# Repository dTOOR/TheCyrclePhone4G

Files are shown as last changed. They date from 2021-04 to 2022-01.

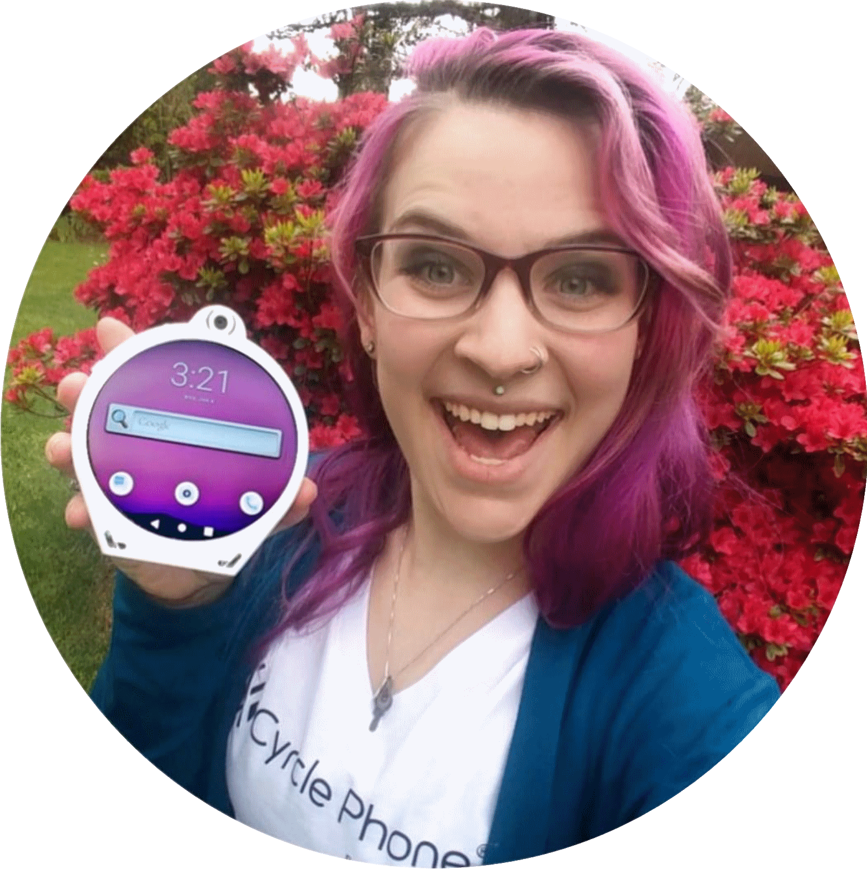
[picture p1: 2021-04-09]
Media/TeresaMicheletti_RoundPhoto_20200414.png

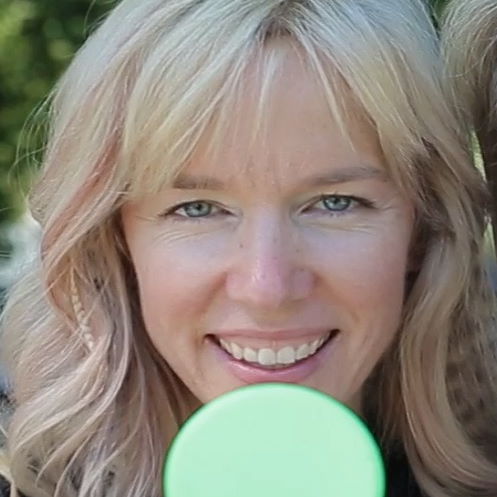
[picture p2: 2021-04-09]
Media/ChristinaGreenPhoneSquareJPG.jpg

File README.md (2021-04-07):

Welcome to the repository for The Cyrcle Phone 4G LTE.

HARDWARE:
Includes the schematics, board layout, and enclosure CAD files.

SOFTWARE:
Includes directions for creating the build.  

LICENSES:
A brief README.md overview and a copy of all the open source licenses which pertain to our product.

MEDIA:
Logos, brand guidelines, team photos

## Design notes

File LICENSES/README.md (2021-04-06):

<h1>LICENSES</h1>

<p>The Cyrcle Phone 4G LTE's software (including AOSP, Linux, and F-Droid) and hardware (including schematics, board layout, and enclosure CAD files) are shared with you under open source licenses, with some limitations due to closed source licenses we have had to sign with suppliers in order to obtain specific components. Mobile phones notoriously have a plethora of open source licenses and private driver licenses to maintain, for both the hardware and software. Communicating these licenses to our users in a clear manner is important to us. </p>

<h2>Open Source Software Licenses</h2>
<p>Below is a list of important open source software licenses which you should be aware of when you modify software provided here. 
We have provided this list to the best of our ability, and do not claim it is all-inclusive. 
We have includes samples of these licenses in our LICENSES folder, but please check with these organizations for the most updated version.</p>
<ul>
         <li>Apache 2.0 (Example: Android Open Source Project)</li>
         <li>GNU GPLv2 (Example: Linux kernel patches)</li>
         <li>GNU GPLv3 (Example: F-Droid)</li>
         <li>Mozilla Public License 2.0 (Example: Firefox, Lightning Browser)</li>
</ul>

<h2>Open Source Hardware Licenses</h2>
<p>Below is a list of important open source hardware licenses which you should be aware of when you modify any open source hardware.
We have provided this list to the best of our ability, and do not claim it is all-inclusive. 
We have includes samples of these licenses in our LICENSES folder, but please check with these organizations for the most updated version.</p>
<ul>
         <li>CERN - Now available in 3 flavors: CERN-OHL-P (permissive), CERN-OHL-W (weakly reciprocal), and CERN-OHL-S (strongly reciprocal)
         Developed by the org which created the world wide web</li>
         <li>TAPR - Tucson Amateur Packet-Radio Open Hardware license, by John Ackerman and FOSS' Bruce Perens</li>
         <li>Solderpad - basically Apache 2.0 but for hardware, by Andrew Katz</li>
         <li>TDPL  - Three-Dimensional Printing Open license by Eli Greenbaum (for enclosures)</li>
         <li>CC by SA - Adafruit, Sparkfun, and Arduino utilize this license</li>
</ul>

<p>It is important to note that The Cyrcle Phone 4G LTE's hardware (including schematics, board layout, and enclosure CAD files) are shared with you under an open source license, with some limitations due to the closed source licenses we have had to sign with suppliers in order to obtain specific components. </p>

<h2>Closed Source Hardware and Software Licenses</h2>
<p>Below is a list of important private licenses which our company has had to sign along our journey of making The Cyrcle Phone 4G LTE of which you should be aware, and which we may not be able to share out to you.
We have provided this list to the best of our ability, and do not claim it is all-inclusive. </p>
<ul>
         <li>Quectel Wireless Solutions Co., Ltd. (Includes the module technology)</li>
         <li>Tianma Microelectronics Co. (Includes the display and touchscreen technology)</li>
</ul>

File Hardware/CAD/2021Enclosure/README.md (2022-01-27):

<p>These are the STL and STEP files for 2021 The Cyrcle Phone 4G enclosure.</p>

<p>Additional Materials Needed:</p>
Uses the following eight (8) McMaster Carr screws (4 for the skeleton, 4 for the back shell)
- 5mm Screws: JIS Steel Flat Head Screws, M1.6 x 0.35 mm Thread, 5mm Long, 91305A004 https://www.mcmaster.com/catalog/127/3293/

<br><p>Tips for printing:</p>
- Calibrate your machine first. The walls are thin and will test your 3D printer's tolerances.
- Print the "back shell" separately, face down, and use rectilinear supports inside to make the back of the shell smooth. Use pliers to grab and twist the support material out from the inside of the "back shell". The inside will end up being rough, but the outside smoothness will feel nice in the hand.
- Print the "faceplate" face down on a glassy surface for a nice and smooth face. We typically use a contrasting color (black) for this piece, and consequently have to print it separately.
- Print the "outer ring" with the tabs up, face down, because you will want the face of the "outer ring" to be smooth, and allow the slight indentations for the ports to print well on top. (You can sand away any irregularities that may occur with the tabs later since they end up hidden in the design.)

<br><p>History:</p>
<br>In July 2020, industrial designer Wesley Millora submitted an entry for The Cyrcle Phone 4G enclosure contest held on MyMiniFactory and won "Best Exterior" out of 64 submissions.
<br>In September 2020, dTOOR solicited Millora for a bid to update the design for injection molding purposes, which he then submitted.
<br>Months rolled by as dTOOR continued to work on software development.
<br>In late December 2020, Millora was contacted by dTOOR Founder & CEO Christina Cyr, formerly asking him to join the team. Since Millora was on vacation, and working on another project at the time, Cyr also asked permission to use Millora's design in the meantime, since units needed to be submitted to China for testing by January 10th.
<br>In short, these files were created by dTOOR Founder & CEO Christina Cyr in January 2021, specifically based on (and only after obtaining consent) Wesley Millora's images submitted for The Cyrcle Phone 4G enclosure design contest on MyMiniFactory, with the intention of Millora joining the team at a later date when he was available. Millora joined the team in March 2021 to update the design for injection molding purposes.
<br>As such, these files are not absolutely identical to the final product, as they have been designed to print (more) reliably on a 3D printer (slightly thicker walls, no 3% wall incline required for injection molding, etc.). These 3D-printer-friendly files were used for all of our evaluation models. In our experience, these files can be printed fairly reliabily with most PLA filaments on most 3D printers, so that you can have any color (or sparkle) you want. These files are also provided to you so that you can enhance the design to better fit your style (rabbit ears, etc.). We would love it if you could share photos of your designs on social media and tag us at #cyrclephone so that we can see what you've added. Have fun!

Licenses:
- The enclosure CAD files are shared under CERN-OHL-W-2.0 open hardware license. https://ohwr.org/project/cernohl/wikis/faq#q-what-are-all-these-suffixes
- This documentation is shared under CC BY-SA 2.0 open license. https://creativecommons.org/licenses/by-sa/2.0/

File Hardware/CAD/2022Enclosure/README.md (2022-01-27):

README.md
These are the STL files for 2022 The Cyrcle Phone 4G enclosure.

Additional Materials Needed:

Uses the following eight (8) McMaster Carr screws (4 for the skeleton, 4 for the back shell) - 5mm Screws: JIS Steel Flat Head Screws, M1.6 x 0.35 mm Thread, 5mm Long, 91305A004 https://www.mcmaster.com/catalog/127/3293/

Tips for printing:

Calibrate your machine first. The walls on this model are thin and will test your 3D printer's tolerances.
Print the "back shell" separately, face down, and use rectilinear supports inside the concave shape to the build platform in order to make the back of the shell smooth. After printing, use pliers to grab and twist the support material out from the inside of the "back shell". The inside will end up being rough, but the outside smoothness will feel nice in the hand.
Print the "faceplate" face down on a glassy surface for a nice and smooth face. We typically use a contrasting color (black) for this piece, and consequently have to print it separately.
Print the "outer ring" with the tabs up, face down, because you will want the face of the "outer ring" to be smooth, and allow the slight indentations for the ports to print well on top. (You can sand away any irregularities that may occur with the tabs later since they end up hidden in the design.)
Print the "skeleton" and "buttons" in any color or material; these are reliable prints on basically any setting.

History:

In July 2020, industrial designer Wesley Millora submitted an entry for The Cyrcle Phone 4G enclosure contest held on MyMiniFactory and won "Best Exterior" out of 64 submissions.
In September 2020, dTOOR solicited Millora for a bid to update the design for injection molding purposes, which he then submitted.
Months rolled by as dTOOR continued to work on software development.
In late December 2020, Millora was contacted by dTOOR Founder & CEO Christina Cyr, formerly asking him to join the team. Since Millora was on vacation, and working on another project at the time, Cyr also asked permission to use Millora's design in the meantime, since units needed to be submitted to China for testing by January 10th.
Millora worked on preparing a design appropriate for injection molding throughout 2021, with his final submission to dTOOR in December 2021. Cyr modified these final files to create a newer 3D printable design.
These 3D-printer-friendly files were used for evaluation models, and one unit was even demonstrated at The Cyrcle Phone booth at CES2022 with positive response. 
In our experience, these files can be printed fairly reliabily with most PLA filaments on most 3D printers, so that you can have any color (or sparkle) you want. These files are also provided to you so that you can enhance the design to better fit your style (rabbit ears, etc.). We would love it if you could share photos of your designs on social media and tag us at #cyrclephone so that we can see what you've added. Have fun!
Licenses:

The enclosure CAD files are shared under CERN-OHL-W-2.0 open hardware license. https://ohwr.org/project/cernohl/wikis/faq#q-what-are-all-these-suffixes
This documentation is shared under CC BY-SA 2.0 open license. https://creativecommons.org/licenses/by-sa/2.0/

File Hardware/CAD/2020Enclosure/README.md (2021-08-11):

These are the files dTOOR Founder & CEO Christina Cyr designed for The Cyrcle Phone 4G enclosure for The Cyrcle Phone booth at CES2020. Important note: This model accommodates the older Tequila PCB, but does not accommodate the new temperature sensor hardware near the selfie camera on the newer Mezcal PCB. We recommend widening the selfie camera housing to accommodate this change, or using the 2021enclosure. 

This model uses the following two (2) McMaster Carr threaded inserts and four (4) screws.

- Threaded inserts: Tapered Heat-Set Inserts For Plastic, Brass, M1.6 x 0.35 Mm Thread Size, 2.92 Mm Installed Length, 94180A501 https://www.mcmaster.com/catalog/127/3569
- 4mm Screws: JIS Steel Flat Head Screws, M1.6 x 0.35 mm Thread, 4mm Long, 91305A003 https://www.mcmaster.com/catalog/127/3293/

Licenses:
- The enclosure CAD files are shared under CERN-OHL-W-2.0 open hardware license. https://ohwr.org/project/cernohl/wikis/faq#q-what-are-all-these-suffixes
- This documentation is shared under CC BY-SA 2.0 open license. https://creativecommons.org/licenses/by-sa/2.0/

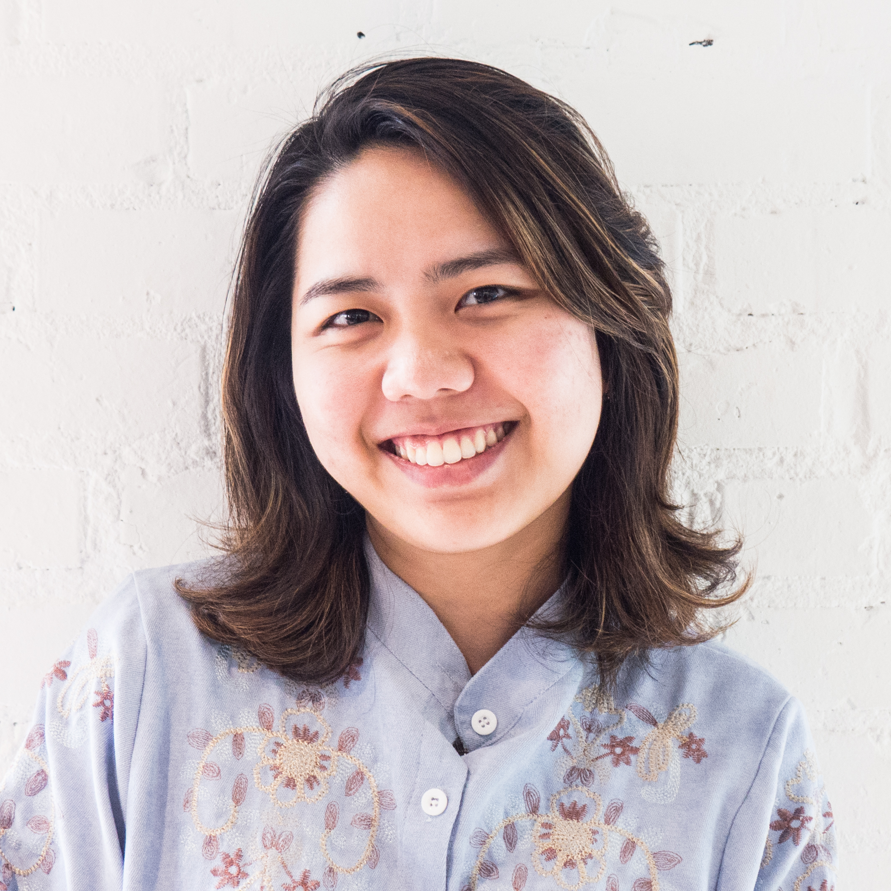
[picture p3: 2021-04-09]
Media/Mai-Dang-Headshot-Publish.jpg

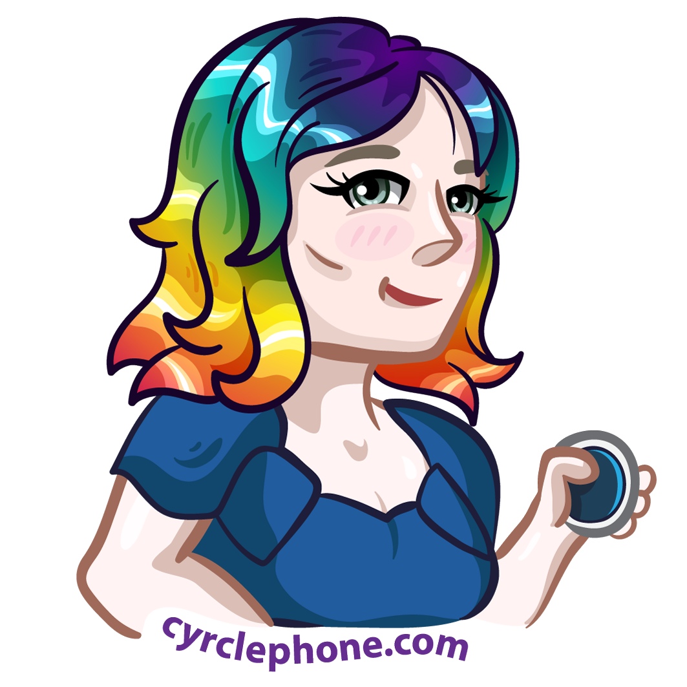
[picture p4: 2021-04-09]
Media/Sticker.png

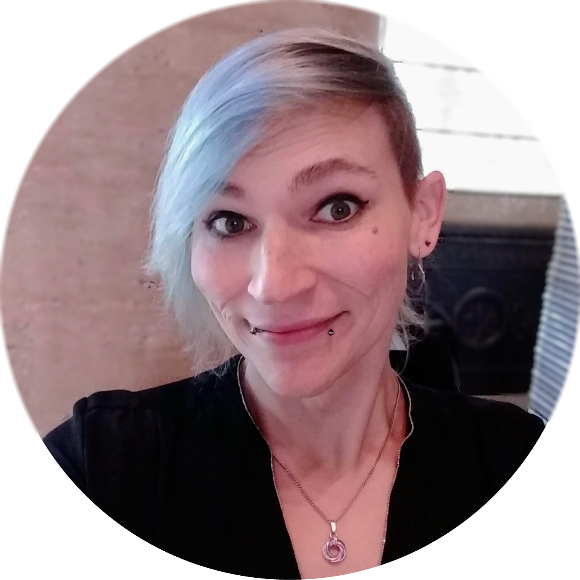
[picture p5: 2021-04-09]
Media/AddisonKarolick.png

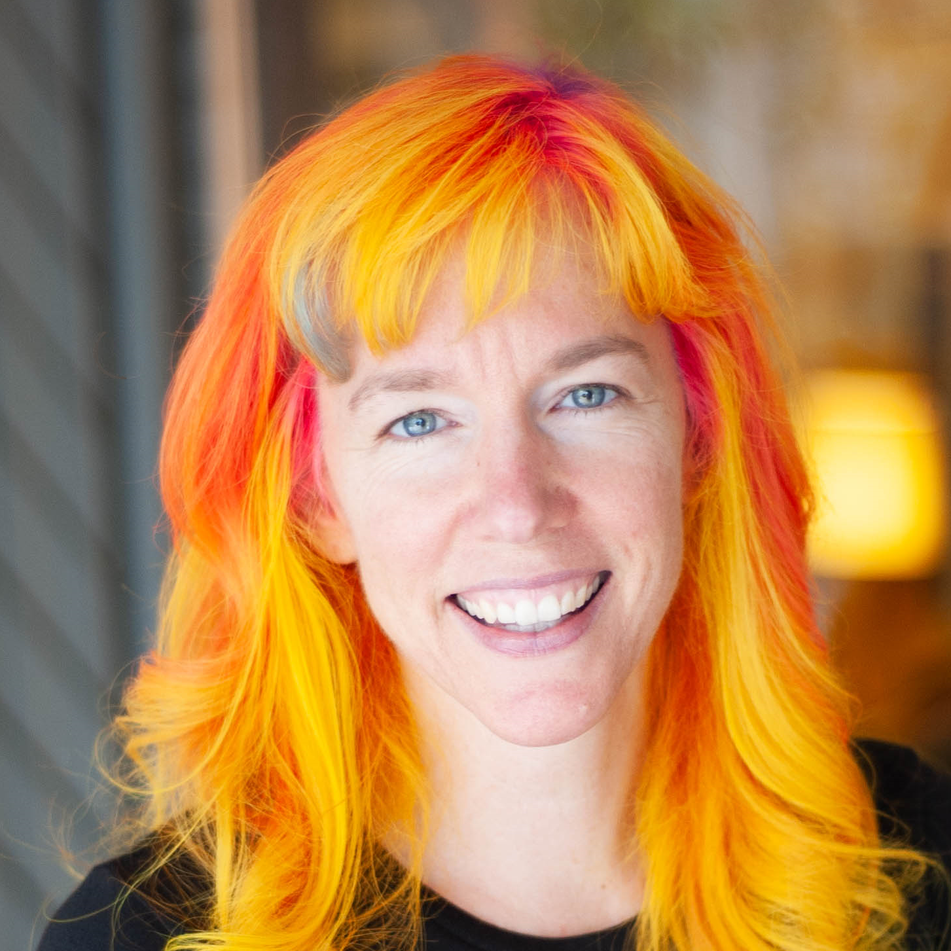
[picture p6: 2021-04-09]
Media/ChristinaCyr_Square.png

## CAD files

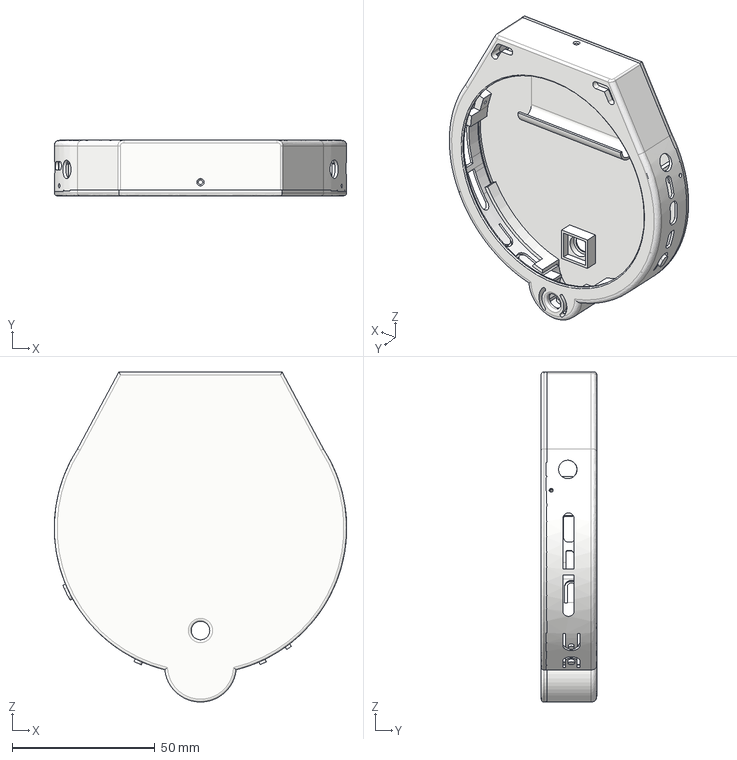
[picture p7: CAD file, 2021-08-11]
Hardware/CAD/2020Enclosure/STEPs/Tequila_20191217_enclosure_20200106 v64.step
102.6 x 19.5 x 115.8 mm

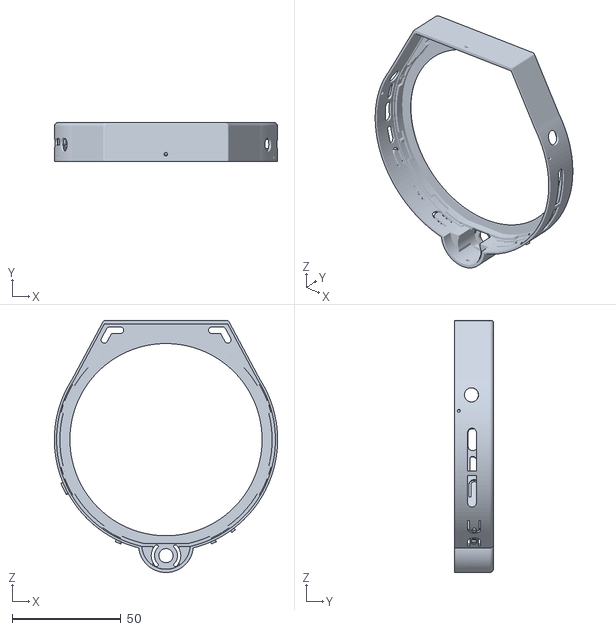
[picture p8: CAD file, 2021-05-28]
Hardware/CAD/2020Enclosure/STLs/Front_20191217_enclosure_20200106 v58.stl
102.6 x 18.0 x 115.8

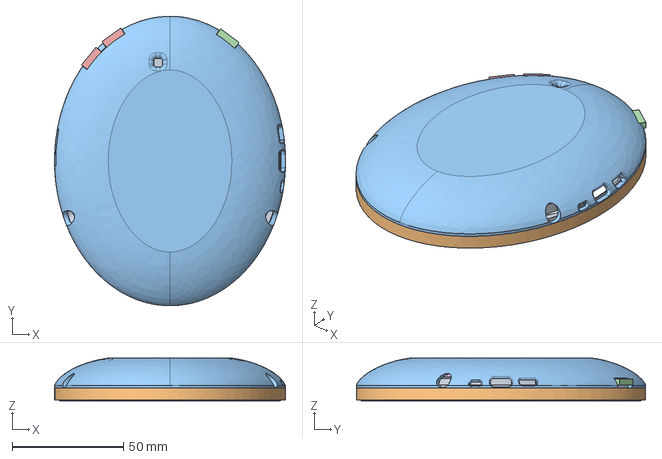
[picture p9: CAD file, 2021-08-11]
Hardware/CAD/2021Enclosure/STEPs/TheCyrclePhone_Mezcal_Oval4 v13.step
103.9 x 130.1 x 19.2 mm

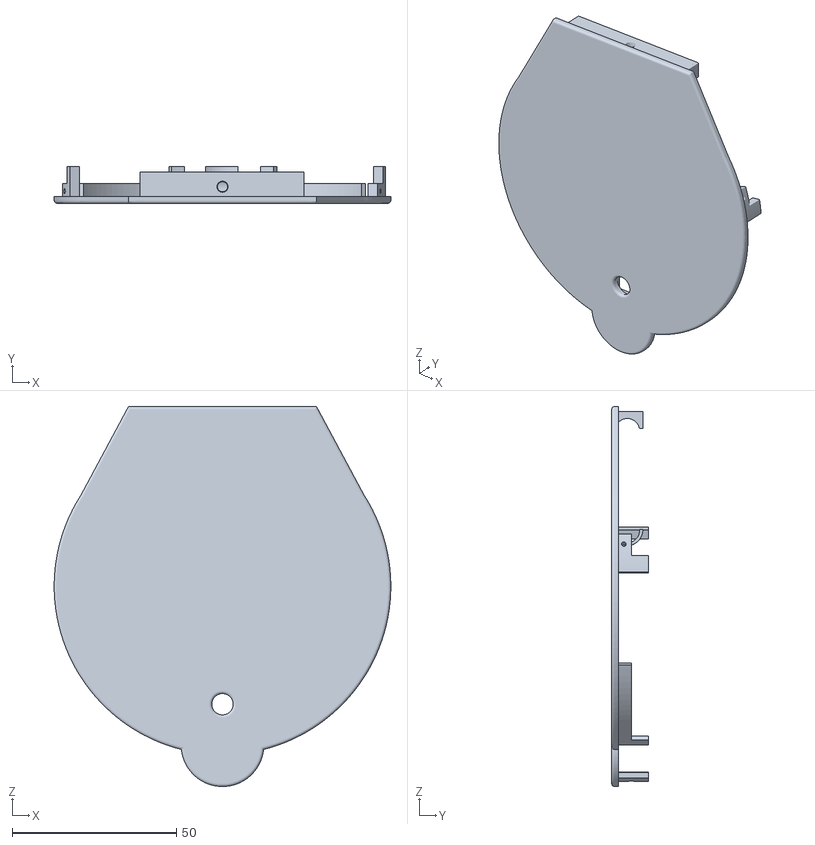
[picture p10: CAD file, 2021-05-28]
Hardware/CAD/2020Enclosure/STLs/Back_20191217_enclosure_20200106 v48.stl
102.6 x 11.2 x 115.8

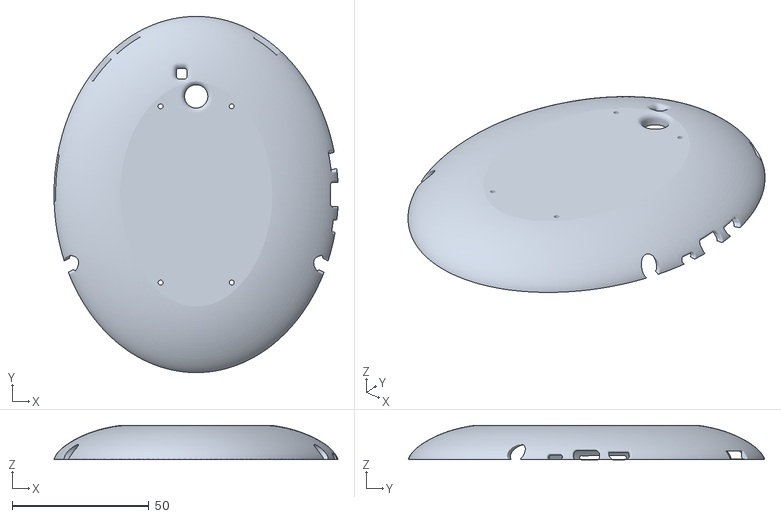
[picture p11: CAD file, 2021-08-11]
Hardware/CAD/2021Enclosure/STLs/20210310_BackShell.stl
103.8 x 130.1 x 12.5

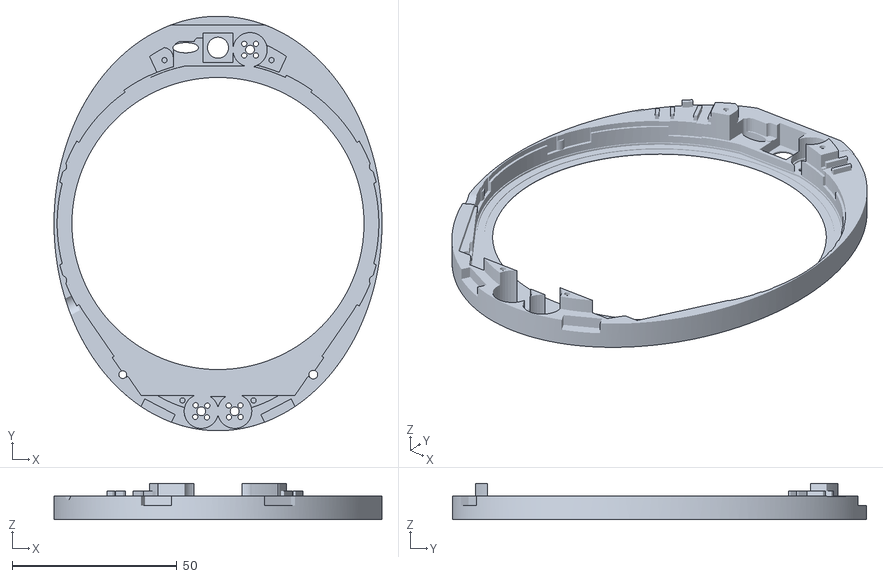
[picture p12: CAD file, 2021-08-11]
Hardware/CAD/2021Enclosure/STLs/20210619_Faceplate.stl
99.5 x 125.7 x 11.0

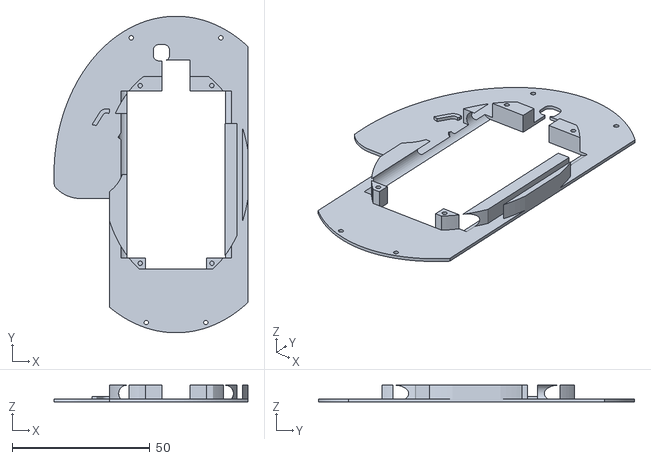
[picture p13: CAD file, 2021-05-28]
Hardware/CAD/2021Enclosure/STLs/20210414_Skeleton.stl
70.3 x 114.7 x 6.00

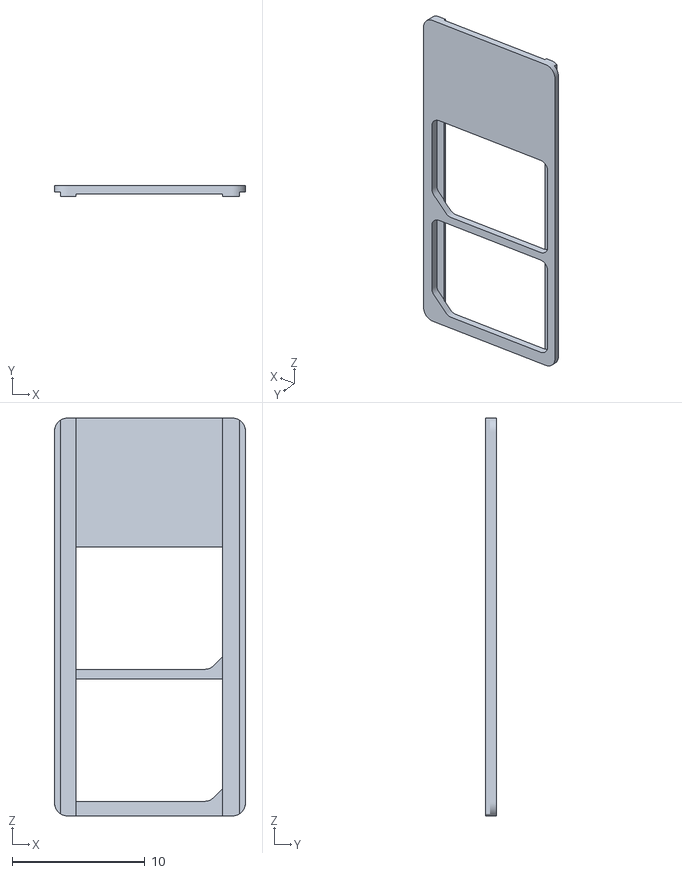
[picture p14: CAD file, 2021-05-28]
Hardware/CAD/2021Enclosure/STLs/20210111_SIMcardtray.stl
14.4 x 0.85 x 30.0

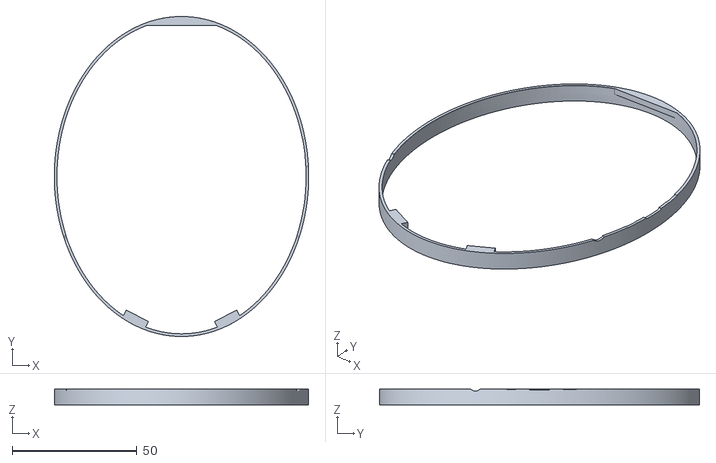
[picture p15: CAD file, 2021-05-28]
Hardware/CAD/2021Enclosure/STLs/20210407_FrontRing_with_HeadphoneJack_holes.stl
101.9 x 128.1 x 6.34

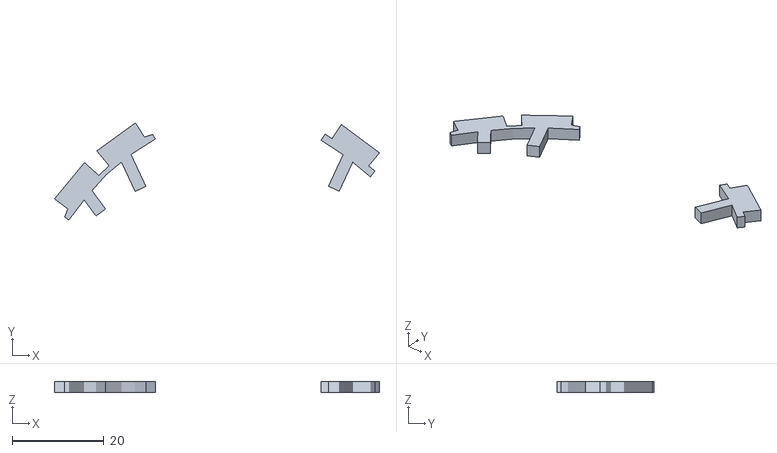
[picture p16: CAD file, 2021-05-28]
Hardware/CAD/2021Enclosure/STLs/20210105_Buttons.stl
70.9 x 21.2 x 2.50

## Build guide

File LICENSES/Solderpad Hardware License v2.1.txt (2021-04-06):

Solderpad Hardware License v2.1
This license operates as a wraparound license to the Apache License Version 2.0 (the “Apache License”) and incorporates the terms and conditions of the Apache License (which can be found here: http://apache.org/licenses/LICENSE-2.0), with the following additions and modifications. It must be read in conjunction with the Apache License. Section 1 below modifies definitions and terminology in the Apache License and Section 2 below replaces Section 2 of the Apache License. The Appendix replaces the Appendix in the Apache License. You may, at your option, choose to treat any Work released under this license as released under the Apache License (thus ignoring all sections written below entirely).

1. Terminology in the Apache License is supplemented or modified as follows:

“Authorship”: any reference to ‘authorship’ shall be taken to read “authorship or design”.

“Copyright owner”: any reference to ‘copyright owner’ shall be taken to read “Rights owner”.

“Copyright statement”: the reference to ‘copyright statement’ shall be taken to read ‘copyright or other statement pertaining to Rights’.

The following new definition shall be added to the Definitions section of the Apache License:

“Rights” means copyright and any similar right including design right (whether registered or unregistered), rights in semiconductor topographies (mask works) and database rights (but excluding Patents and Trademarks).

The following definitions shall replace the corresponding definitions in the Apache License:

“License” shall mean this Solderpad Hardware License version 2.1, being the terms and conditions for use, manufacture, instantiation, adaptation, reproduction, and distribution as defined by Sections 1 through 9 of this document.

“Licensor” shall mean the owner of the Rights or entity authorized by the owner of the Rights that is granting the License.

“Derivative Works” shall mean any work, whether in Source or Object form, that is based on (or derived from) the Work and for which the editorial revisions, annotations, elaborations, or other modifications represent, as a whole, an original work of authorship or design. For the purposes of this License, Derivative Works shall not include works that remain reversibly separable from, or merely link (or bind by name) or physically connect to or interoperate with the Work and Derivative Works thereof.

“Object” form shall mean any form resulting from mechanical transformation or translation of a Source form or the application of a Source form to physical material, including but not limited to compiled object code, generated documentation, the instantiation of a hardware design or physical object or material and conversions to other media types, including intermediate forms such as bytecodes, FPGA bitstreams, moulds, artwork and semiconductor topographies (mask works).

“Source” form shall mean the preferred form for making modifications, including but not limited to source code, net lists, board layouts, CAD files, documentation source, and configuration files.

“Work” shall mean the work of authorship or design, whether in Source or Object form, made available under the License, as indicated by a notice relating to Rights that is included in or attached to the work (an example is provided in the Appendix below).

2. Grant of License. Subject to the terms and conditions of this License, each Contributor hereby grants to You a perpetual, worldwide, non-exclusive, no-charge, royalty-free, irrevocable license under the Rights to reproduce, prepare Derivative Works of, make, adapt, repair, publicly display, publicly perform, sublicense, and distribute the Work and such Derivative Works in Source or Object form and do anything in relation to the Work as if the Rights did not exist.

APPENDIX

Copyright [yyyy] [name of copyright owner]
SPDX-License-Identifier: Apache-2.0 WITH SHL-2.1

Licensed under the Solderpad Hardware License v 2.1 (the “License”); you may not use this file except in compliance with the License, or, at your option, the Apache License version 2.0. You may obtain a copy of the License at

https://solderpad.org/licenses/SHL-2.1/

Unless required by applicable law or agreed to in writing, any work distributed under the License is distributed on an “AS IS” BASIS, WITHOUT WARRANTIES OR CONDITIONS OF ANY KIND, either express or implied. See the License for the specific language governing permissions and limitations under the License.

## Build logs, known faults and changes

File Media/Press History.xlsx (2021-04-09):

Date Published | Channel & Article Link | Journalist | Key Quote
2016-12-14 | King 5 Evening News (https://www.king5.com/article/entertainment/television/programs/evening/seattles-startup-community-sticks-together/281-369995036) | Saint Bryan | "To work for yourself, you kinda need to be scrappy, so you gotta get in there with some grit and tenacity because it's really lonely," Cyr says.
2016-03-11 | Business Insider (https://www.businessinsider.com/what-is-cyrcle-phone-2016-3) | Rafi Letzter | What does a smartphone look like? A rectangle, about the size of an index card, usually either white, black, or chrome.
2016-03-03 | Independent UK (https://www.independent.co.uk/life-style/gadgets-and-tech/news/cyrcle-round-circle-circular-smartphone-dtoor-mobile-world-congress-a6909306.html) | Doug Bolton | The Cyrcle phone is designed to be more elegant and ladylike than its rectangular competitors
2016-02-29 | 3ders.org (https://www.3ders.org/articles/20160229-cyrcle-the-3d-printed-circular-smartphone-is-anything-but-square.html) | Tess Boissonneault | Whether you are partial to iPhones, or prefer Samsungs, HTC’s, or LG’s, it is hard to escape one common factor between them: the smartphones on the market are practically all rectangular these days.
2016-02-28 | CNET (https://www.cnet.com/news/dtoor-cyrcle-sick-of-phones-that-look-the-same-make-cyrcle/) | RICHARD TRENHOLM | The Cyrcle is a neat example of a device that does things a little differently, conceived by someone who decided to change things for herself.

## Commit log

2021-05-28 2021 Enclosure Files
    [20210105_Buttons.stl, 20210111_SIMcardtray.stl, 20210407_BackShell.stl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]
2021-05-28 2020 Enclosure Files
    [Back_20191217_enclosure_20200106 v48.stl, Front_20191217_enclosure_20200106 v58.stl]
2021-05-28 Included screw information
2021-08-11 Rename R.md to README.md
    These are the files dTOOR Founder & CEO Christina Cyr designed for The Cyrcle Phone 4G enclosure for The Cyrcle Phone booth at CES2020. Important note: This model accommodates the older Tequila PCB, 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
    Threaded inserts: Tapered Heat-Set Inserts For Plastic, Brass, M1.6 x 0.35 Mm Thread Size, 2.92 Mm Installed Length, 94180A501 https://www.mcmaster.com/catalog/127/3569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
2021-08-11 Added F3Z and STEP files
    [Tequila_20191217_enclosure_20200106 v64.step]
2021-08-11 Create README.md
    <p>These are the F3Z files for 2021 The Cyrcle Phone 4G enclosure.</p>
    <p>Additional Materials Needed for Assembly:</p>
    Uses the following eight (8) McMaster Carr screws (4 for the skeleton, 4 for the back shell)
    - 5mm Screws: JIS Steel Flat Head Screws, M1.6 x 0.35 mm Thread, 5mm Long, 91305A004 https://www.mcmaster.com/catalog/127/3293/
    <br><p>Tips for printing:</p>
    - Calibrate your machine first. The walls are thin and will test your 3D printer's tolerances.
    - Print the "back shell" separately, face down, and use rectilinear supports inside to make the back of the shell smooth. Use pliers to grab and twist the support material out from the inside of the "back sh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
